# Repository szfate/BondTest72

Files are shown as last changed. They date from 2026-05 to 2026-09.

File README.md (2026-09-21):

# BondTest72

Production test fixture board for bond wire testing, controlled by a Raspberry Pi Pico.
Test signals are routed through CH446X analog crosspoint switches to two 41-pin connectors, on which a replaceable adapter board sits. The adapter board carries the DUT connector and any auxiliary components, keeping the main tester board from wearing out.

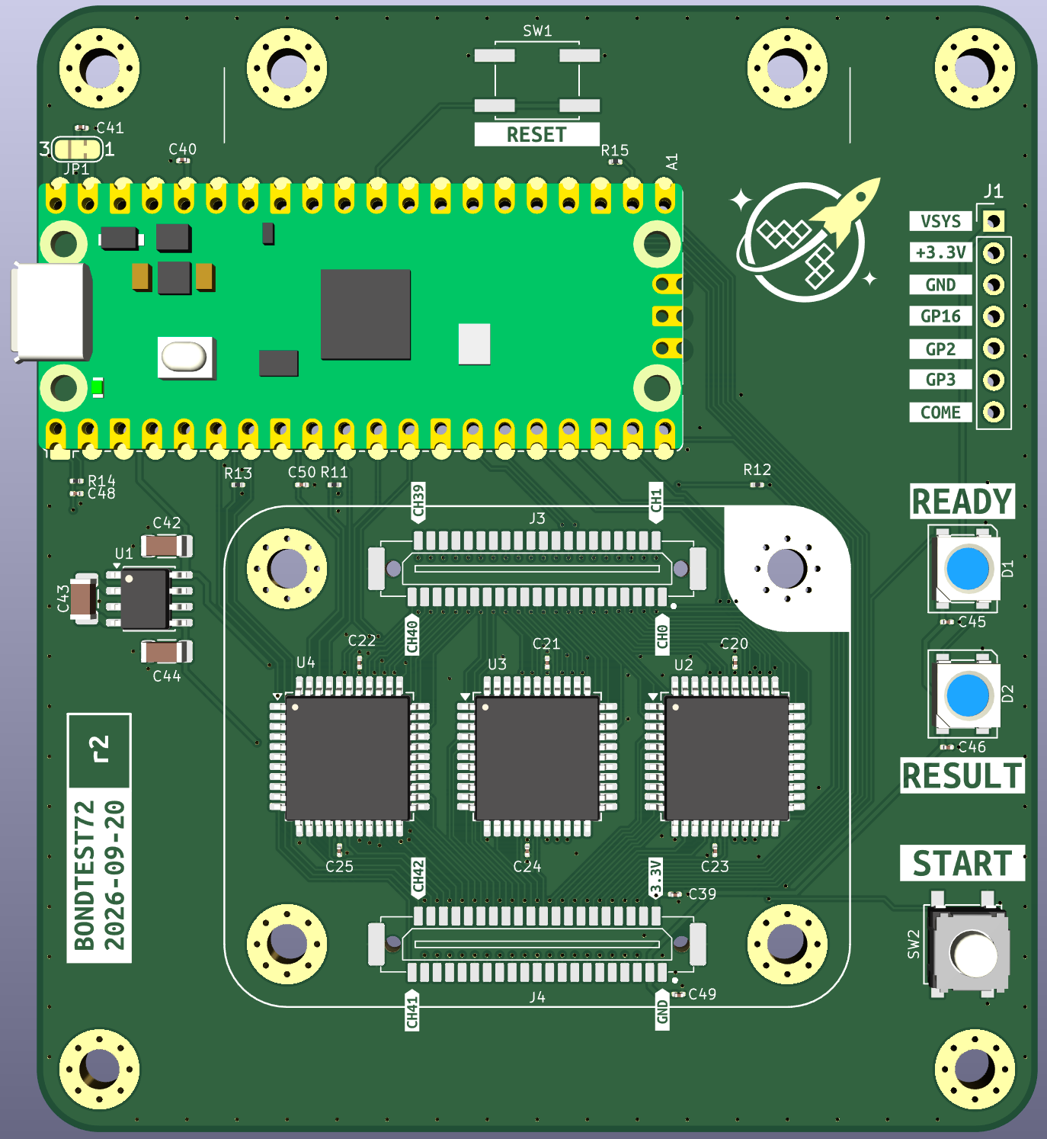
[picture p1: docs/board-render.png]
Board render


## Specifications

| Parameter | Value |
|---|---|
| Revision | r2 |
| Date | 2026-09-20 |
| Board size | 80 × 90 mm |
| Layers | 4 (F.Cu / In1.Cu / In2.Cu / B.Cu) |
| Thickness | 1.6 mm FR4 |

## Power

The board is powered from the Pico's USB VBUS rail. The TPS7A0533 LDO provides an optional quiet +3.3VADC rail as an alternative ADC reference, in case the main +3.3V rail from the Pico's onboard DCDC is too noisy. In practice the application only requires ~0.1 V accuracy, so the main rail is likely sufficient.

An ICL7660 charge-pump voltage inverter (or equivalent) generates the negative VEE rail required by the CH446X analog crosspoint switches.

## Operator Interface

A single push button serves as the START control. The two SK6812 RGB LEDs serve as status indicators. Both the LEDs and the button sit on the right edge of the board so the prodcution panel cannot cover them.

## Signal Routing

Four CH446X analog crosspoint switches fan test signals out from the Pico GPIO/ADC lines to the 41-pin connectors (J3 / J4). These connect to a removable **adapter board** rather than directly to the DUT. The adapter board carries the DUT-side connector (the high-wear part) and any auxiliary components needed for a given test configuration — for example, diodes for self-testing or a small memory chip for wear-cycle monitoring. Replacing the adapter board instead of the whole fixture avoids discarding the tester after the DUT connector wears out (~100 cycles). Solder jumpers on the main board provide flexibility to work around any schematic design flaws discovered after fabrication.

## Revision History

### r2 (2026-09-21)

Schematic:
- Neighbour testing removed, replaced with 10 µA / 100 µA / 1 mA current sources; pullup resistors (280 kΩ / 27.4 kΩ / 2.49 kΩ) sized from the expected diode voltage drop at each current
- ICL7660 (or alternative) added for the negative VEE supply
- 100 kΩ pulldown on Pico pad 22 (CON6, EEPROM SIO)
- 10 kΩ pullup on Pico pad 1 (START) per the RP2350 A2 errata
- 120 pF capacitor added to the ADC sensing net
- Status LEDs reduced from three to two SK6812
- Push button changed to EVP-BT3C4A000; r1's alternate second switch footprint removed

PCB:
- Board size reduced from 80 × 100 mm to 80 × 90 mm
- LEDs and button moved to the right side of the board so the panel no longer covers the LEDs; Space left for button caps
- Feet marks on the bottom silk enlarged from 8 mm to 10 mm

### r1 (2026-05-12)

Initial release. 80 × 100 mm.

## Files

| File | Description |
|---|---|
| `BondTest72.kicad_pro` | KiCad project |
| `BondTest72.kicad_sch` | Schematic |
| `BondTest72.kicad_pcb` | PCB layout |
| `docs/BondTest72-r2-schematic.pdf` | r2 schematic PDF export |
| `docs/BondTest72-r1-schematic.pdf` | r1 schematic PDF export |
| `production/BondTest72-r2.zip` | r2 gerber/fabrication outputs |
| `production/BondTest72-r2-bom.csv` | r2 bill of materials |
| `production/BondTest72-r2-pos.xlsx` | r2 pick-and-place positions |
| `lib.kicad_sym` | Project symbol library |
| `lib.pretty/` | Project footprint library |
| `df9.pretty/` | Additional footprint library |
| `docs/` | Board renders and documentation images |

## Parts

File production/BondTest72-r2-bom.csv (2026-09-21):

Reference | Qty | Value | DNP | Exclude from BOM | Exclude from Board | Footprint | Datasheet | Part Number
A1 | 1 | RaspberryPi_Pico |  |  |  | Module:RaspberryPi_Pico_Common_Unspecified | https://datasheets.raspberrypi.com/pico/pico-datasheet.pdf | C41407547
C20,C21,C22,C23,C24,C25,C39,C45,C46,C48,C49 | 11 | 100n |  |  |  | Capacitor_SMD:C_0201_0603Metric |  | C76939
C40,C41 | 2 | 1u |  |  |  | Capacitor_SMD:C_0201_0603Metric |  | C170153
C42,C43,C44 | 3 | 10u |  |  |  | Capacitor_SMD:C_1206_3216Metric |  | C9807
C50 | 1 | 120pF |  |  |  | Capacitor_SMD:C_0201_0603Metric |  | C161405
D1,D2 | 2 | SK6812 |  |  |  | LED_SMD:LED_SK6812_PLCC4_5.0x5.0mm_P3.2mm | https://cdn-shop.adafruit.com/product-files/1138/SK6812+LED+datasheet+.pdf | C5378720
J1 | 1 | Conn_01x07 | DNP |  |  | Connector_PinHeader_2.54mm:PinHeader_1x07_P2.54mm_Vertical
J3,J4 | 2 | Conn_2Rows-41Pins_MountingPin |  |  |  | df9:DF9-41P-1V |  | C21261706
R11 | 1 | 27.4K |  |  |  | Resistor_SMD:R_0201_0603Metric |  | C273316
R12 | 1 | 2.49k |  |  |  | Resistor_SMD:R_0201_0603Metric |  | C851701
R13 | 1 | 280k |  |  |  | Resistor_SMD:R_0201_0603Metric |  | C778392
R14 | 1 | 10k |  |  |  | Resistor_SMD:R_0201_0603Metric |  | C106225
R15 | 1 | 100k |  |  |  | Resistor_SMD:R_0201_0603Metric |  | C106224
SW1 | 1 | SW_Push |  |  |  | Button_Switch_SMD:SW_SPST_EVQQ2 |  | C713484
SW2 | 1 | SW_Push |  |  |  | Button_Switch_SMD:SW_SPST_EVPBF |  | C4365008
U1 | 1 | ICL7660 |  |  |  | Package_SO:SOIC-8_3.9x4.9mm_P1.27mm | http://datasheets.maximintegrated.com/en/ds/ICL7660-MAX1044.pdf | C356724
U2,U3,U4 | 3 | CH446X |  |  |  | Package_QFP:LQFP-44_10x10mm_P0.8mm |  | C3018882

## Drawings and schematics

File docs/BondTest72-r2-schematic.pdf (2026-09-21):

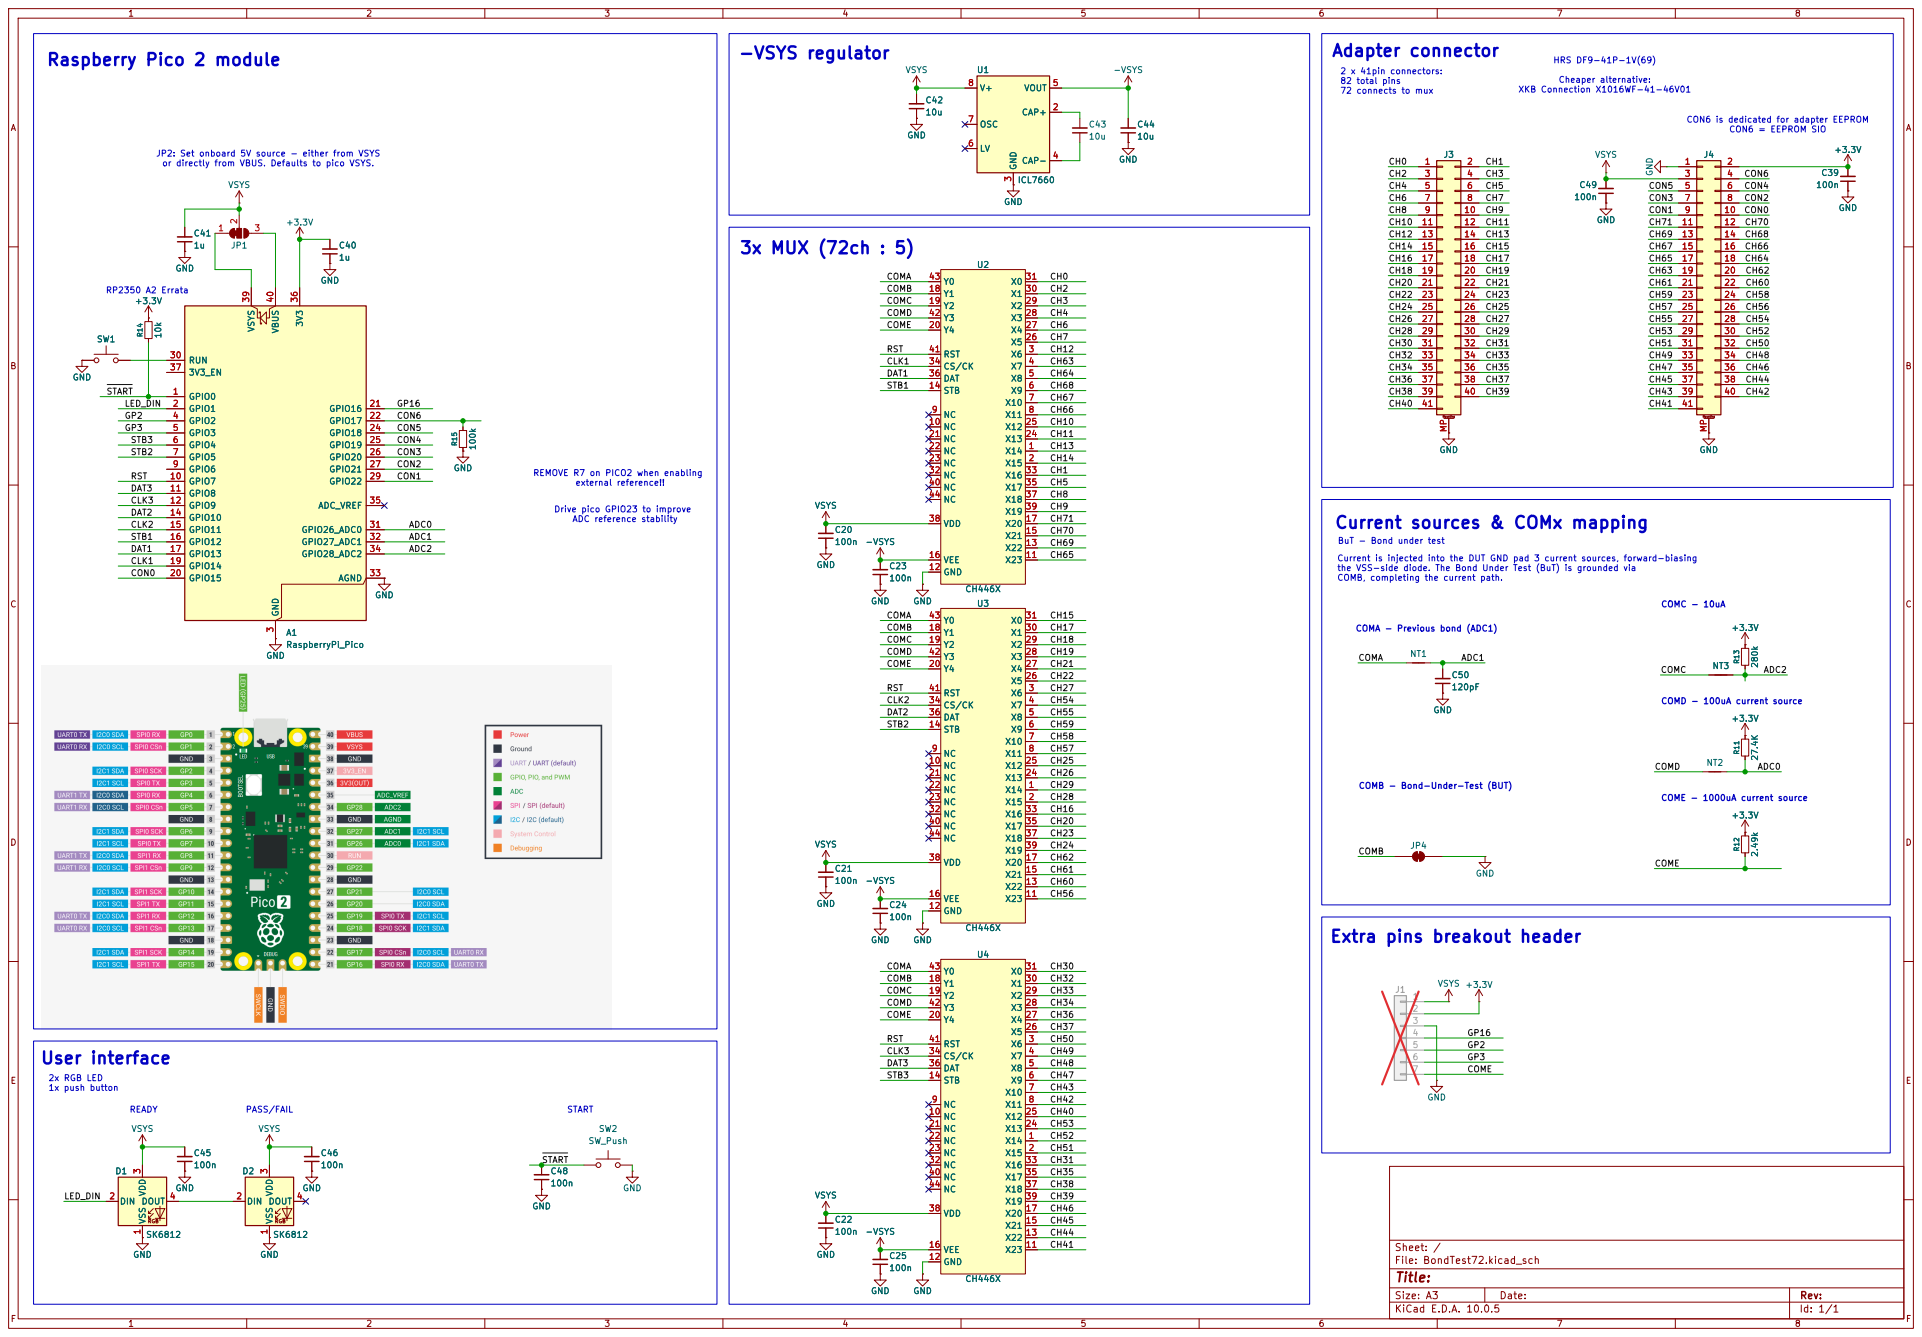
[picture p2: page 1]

CON6 = EEPROM SIO -VSYS regulator

Cheaper alternative: XKB Connection X1016WF-41-46V01 3x MUX (72ch : 5)

CON6 is dedicated for adapter EEPROM

JP2: Set onboard 5V source - either from VSYS

COMA - Previous bond (ADC1) Current is injected into the DUT GND pad 3 current sources, forward-biasing

the VSS-side diode. The Bond Under Test (BuT) is grounded via COMB, completing the current path. START

Extra pins breakout header

Size: A3 | Rev: | F Date:
KiCad E.D.A. 10.0.5 | Id: 1/1

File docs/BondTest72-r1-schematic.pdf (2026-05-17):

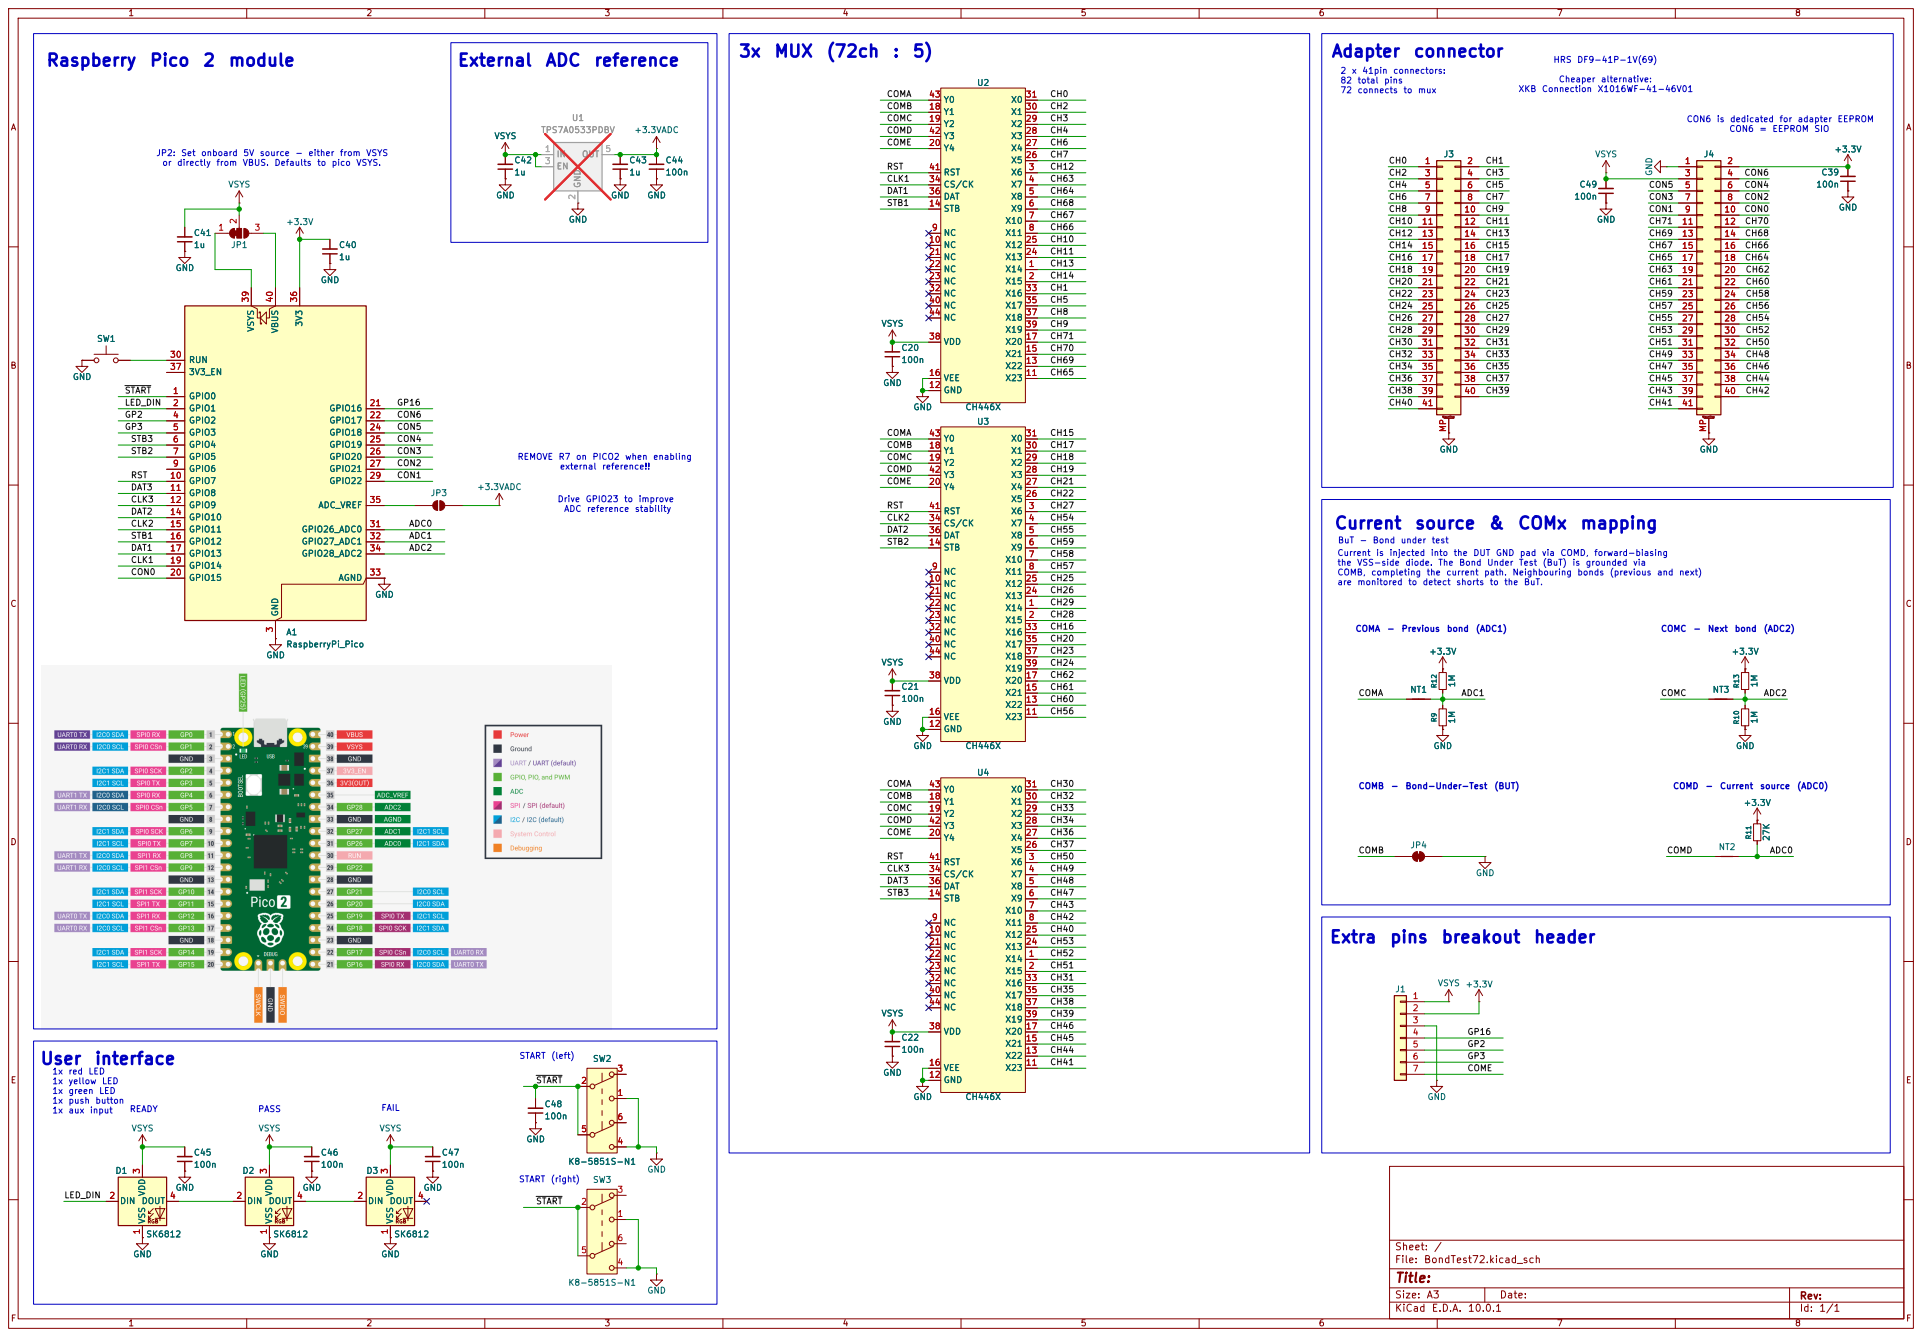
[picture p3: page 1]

Cheaper alternative: XKB Connection X1016WF-41-46V01 Adapter connector

or directly from VBUS. Defaults to pico VSYS. Raspberry Pico 2 module

2 x 41pin connectors: 82 total pins 72 connects to mux

CON6 is dedicated for adapter EEPROM

CON6 = EEPROM SIO Current source & COMx mapping

JP2: Set onboard 5V source - either from VSYS

REMOVE R7 on PICO2 when enabling external reference!! Drive GPIO23 to improve ADC reference stability

BuT - Bond under test COMA - Previous bond (ADC1)
Current is injected into the DUT GND pad via COMD, forward-biasing

the VSS-side diode. The Bond Under Test (BuT) is grounded via COMB, completing the current path. Neighbouring bonds (previous and next) are monitored to detect shorts to the BuT. START (left)

COMD - Current source (ADC0) PASS User interface 1x red LED

COMB - Bond-Under-Test (BUT)

Size: A3 | Rev: | F Date:
KiCad E.D.A. 10.0.1 | Id: 1/1

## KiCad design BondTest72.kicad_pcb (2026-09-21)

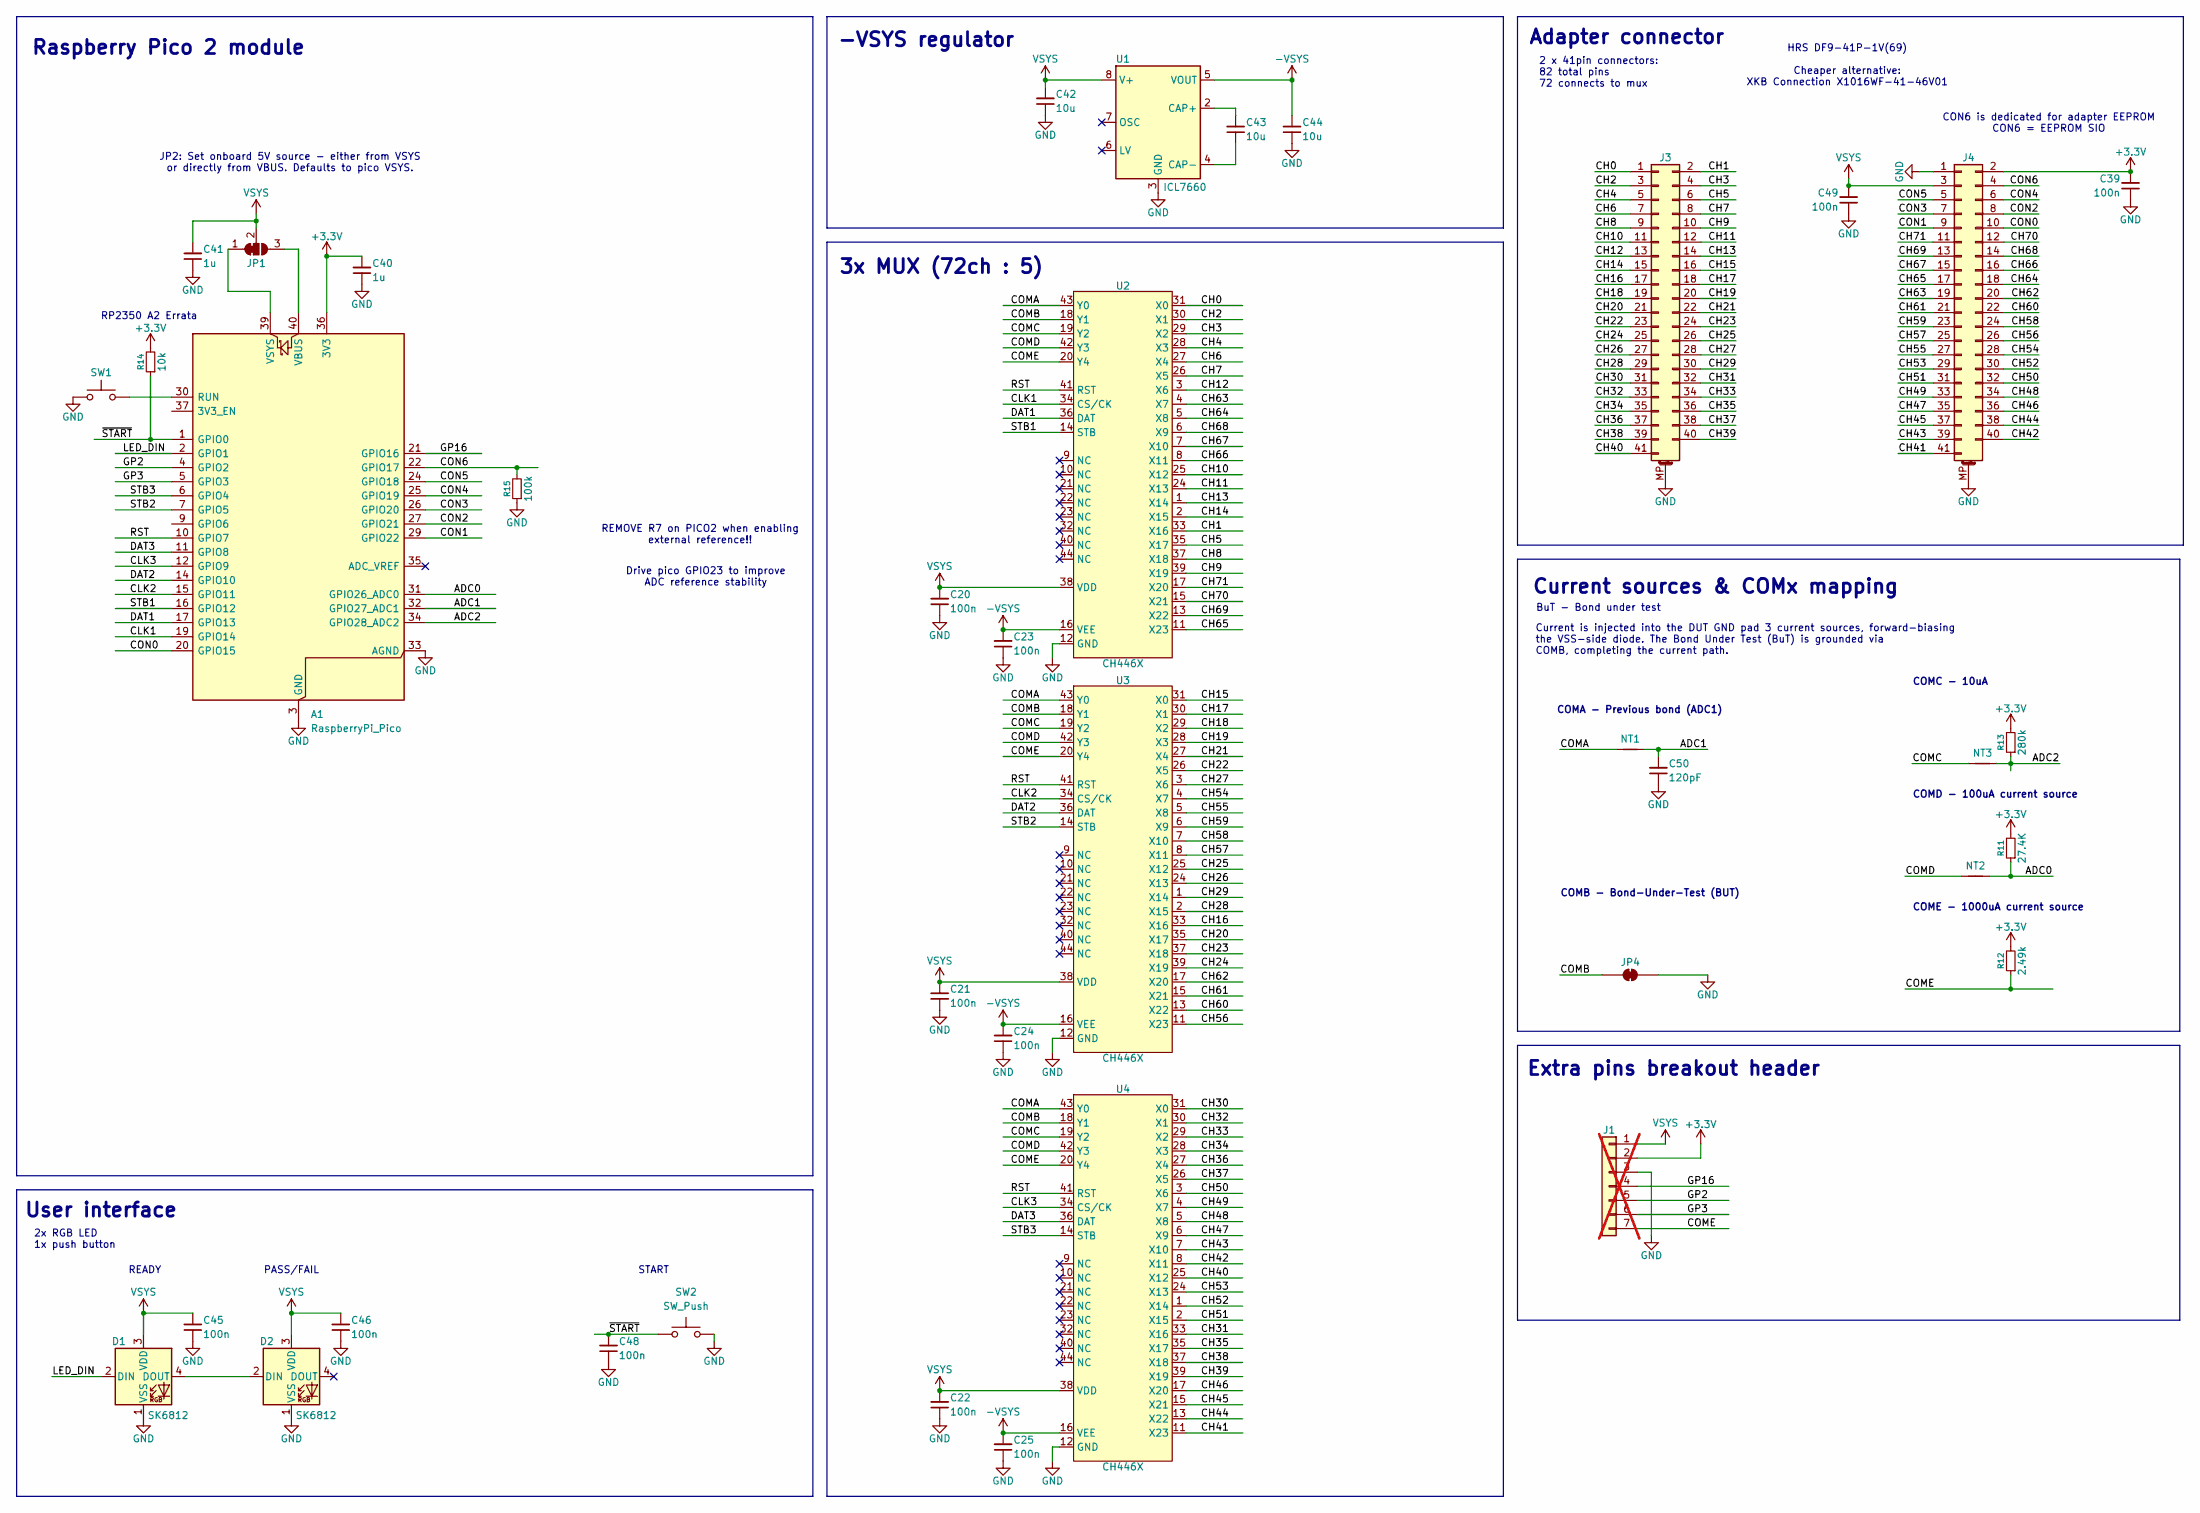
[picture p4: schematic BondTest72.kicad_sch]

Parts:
A1: RaspberryPi_Pico; RaspberryPi_Pico_Common_Unspecified; Part Number C41407547
C20, C21, C22, C23, C24, C25, C39, C45, C46, C48, C49: 100n; C_0201_0603Metric; Part Number C76939
C40, C41: 1u; C_0201_0603Metric; Part Number C170153
C42, C43, C44: 10u; C_1206_3216Metric; Part Number C9807
C50: 120pF; C_0201_0603Metric; Part Number C161405
D1, D2: SK6812; LED_SK6812_PLCC4_5.0x5.0mm_P3.2mm; Part Number C5378720
J1: Conn_01x07; PinHeader_1x07_P2.54mm_Vertical; not fitted
J3, J4: Conn_2Rows-41Pins_MountingPin; DF9-41P-1V; Part Number C21261706
JP1: SolderJumper_3_Bridged12; SolderJumper-3_P1.3mm_Bridged12_RoundedPad1.0x1.5mm_NumberL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
JP4: SolderJumper_2_Bridged; SolderJumper-2_P1.3mm_Bridged_RoundedPad1.0x1.5mm
NT1, NT2, NT3: NetTie_2; NetTie-2_SMD_Pad0.15mm
R11: 27.4K; R_0201_0603Metric; Part Number C273316
R12: 2.49k; R_0201_0603Metric; Part Number C851701
R13: 280k; R_0201_0603Metric; Part Number C778392
R14: 10k; R_0201_0603Metric; Part Number C106225
R15: 100k; R_0201_0603Metric; Part Number C106224
SW1: SW_Push; SW_SPST_EVQQ2; Part Number C713484
SW2: SW_Push; SW_SPST_EVPBF; Part Number C4365008
U1: ICL7660; SOIC-8_3.9x4.9mm_P1.27mm; Part Number C356724
U2, U3, U4: CH446X; LQFP-44_10x10mm_P0.8mm; Part Number C3018882

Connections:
+3.3V: A1.36 (3V3), C39.2, C40.2, J1.2, J4.2, R11.2, R12.2, R13.2, R14.2
-VSYS: C23.2, C24.2, C25.2, C44.2, U1.5 (VOUT), U2.16 (VEE), U3.16 (VEE), U4.16 (VEE)
/ADC0: A1.31 (GPIO26_ADC0), NT2.2, R11.1
/ADC1: A1.32 (GPIO27_ADC1), C50.2, NT1.2
/ADC2: A1.34 (GPIO28_ADC2), NT3.2, R13.1
/CH0: J3.1, U2.31 (X0)
/CH1: J3.2, U2.33 (X16)
/CH2: J3.3, U2.30 (X1)
/CH3: J3.4, U2.29 (X2)
/CH4: J3.5, U2.28 (X3)
/CH5: J3.6, U2.35 (X17)
/CH6: J3.7, U2.27 (X4)
/CH7: J3.8, U2.26 (X5)
/CH8: J3.9, U2.37 (X18)
/CH9: J3.10, U2.39 (X19)
/CH10: J3.11, U2.25 (X12)
/CH11: J3.12, U2.24 (X13)
/CH12: J3.13, U2.3 (X6)
/CH13: J3.14, U2.1 (X14)
/CH14: J3.15, U2.2 (X15)
/CH15: J3.16, U3.31 (X0)
/CH16: J3.17, U3.33 (X16)
/CH17: J3.18, U3.30 (X1)
/CH18: J3.19, U3.29 (X2)
/CH19: J3.20, U3.28 (X3)
/CH20: J3.21, U3.35 (X17)
/CH21: J3.22, U3.27 (X4)
/CH22: J3.23, U3.26 (X5)
/CH23: J3.24, U3.37 (X18)
/CH24: J3.25, U3.39 (X19)
/CH25: J3.26, U3.25 (X12)
/CH26: J3.27, U3.24 (X13)
/CH27: J3.28, U3.3 (X6)
/CH28: J3.29, U3.2 (X15)
/CH29: J3.30, U3.1 (X14)
/CH30: J3.31, U4.31 (X0)
/CH31: J3.32, U4.33 (X16)
/CH32: J3.33, U4.30 (X1)
/CH33: J3.34, U4.29 (X2)
/CH34: J3.35, U4.28 (X3)
/CH35: J3.36, U4.35 (X17)
/CH36: J3.37, U4.27 (X4)
/CH37: J3.38, U4.26 (X5)
/CH38: J3.39, U4.37 (X18)
/CH39: J3.40, U4.39 (X19)
/CH40: J3.41, U4.25 (X12)
/CH41: J4.41, U4.11 (X23)
/CH42: J4.40, U4.8 (X11)
/CH43: J4.39, U4.7 (X10)
/CH44: J4.38, U4.13 (X22)
/CH45: J4.37, U4.15 (X21)
/CH46: J4.36, U4.17 (X20)
/CH47: J4.35, U4.6 (X9)
/CH48: J4.34, U4.5 (X8)
/CH49: J4.33, U4.4 (X7)
/CH50: J4.32, U4.3 (X6)
/CH51: J4.31, U4.2 (X15)
/CH52: J4.30, U4.1 (X14)
/CH53: J4.29, U4.24 (X13)
/CH54: J4.28, U3.4 (X7)
/CH55: J4.27, U3.5 (X8)
/CH56: J4.26, U3.11 (X23)
/CH57: J4.25, U3.8 (X11)
/CH58: J4.24, U3.7 (X10)
/CH59: J4.23, U3.6 (X9)
/CH60: J4.22, U3.13 (X22)
/CH61: J4.21, U3.15 (X21)
/CH62: J4.20, U3.17 (X20)
/CH63: J4.19, U2.4 (X7)
/CH64: J4.18, U2.5 (X8)
/CH65: J4.17, U2.11 (X23)
/CH66: J4.16, U2.8 (X11)
/CH67: J4.15, U2.7 (X10)
/CH68: J4.14, U2.6 (X9)
/CH69: J4.13, U2.13 (X22)
/CH70: J4.12, U2.15 (X21)
/CH71: J4.11, U2.17 (X20)
/CLK1: A1.19 (GPIO14), U2.34 (CS/CK)
/CLK2: A1.15 (GPIO11), U3.34 (CS/CK)
/CLK3: A1.12 (GPIO9), U4.34 (CS/CK)
/COMA: NT1.1, U2.43 (Y0), U3.43 (Y0), U4.43 (Y0)
/COMB: JP4.1 (A), U2.18 (Y1), U3.18 (Y1), U4.18 (Y1)
/COMC: NT3.1, U2.19 (Y2), U3.19 (Y2), U4.19 (Y2)
/COMD: NT2.1, U2.42 (Y3), U3.42 (Y3), U4.42 (Y3)
/COME: J1.7, R12.1, U2.20 (Y4), U3.20 (Y4), U4.20 (Y4)
/CON0: A1.20 (GPIO15), J4.10
/CON1: A1.29 (GPIO22), J4.9
/CON2: A1.27 (GPIO21), J4.8
/CON3: A1.26 (GPIO20), J4.7
/CON4: A1.25 (GPIO19), J4.6
/CON5: A1.24 (GPIO18), J4.5
/CON6: A1.22 (GPIO17), J4.4, R15.2
/DAT1: A1.17 (GPIO13), U2.36 (DAT)
/DAT2: A1.14 (GPIO10), U3.36 (DAT)
/DAT3: A1.11 (GPIO8), U4.36 (DAT)
/GP2: A1.4 (GPIO2), J1.5
/GP3: A1.5 (GPIO3), J1.6
/GP16: A1.21 (GPIO16), J1.4
/LED_DIN: A1.2 (GPIO1), D1.2 (DIN)
/RST: A1.10 (GPIO7), U2.41 (RST), U3.41 (RST), U4.41 (RST)
/STB1: A1.16 (GPIO12), U2.14 (STB)
/STB2: A1.7 (GPIO5), U3.14 (STB)
/STB3: A1.6 (GPIO4), U4.14 (STB)
/~START: A1.1 (GPIO0), C48.2, R14.1, SW2.1
GND: A1.3 (GND), A1.8 (GND), A1.13 (GND), A1.18 (GND), A1.23 (GND), A1.28 (GND), A1.33 (AGND), A1.38 (GND), C20.1, C21.1, C22.1, C23.1, C24.1, C25.1, C39.1, C40.1, C41.1, C42.1, C44.1, C45.1, C46.1, C48.1, C49.1, C50.1, D1.1 (VSS), D2.1 (VSS), J1.3, J3.MP (MountPin), J4.1, J4.MP (MountPin), JP4.2 (B), R15.1, SW1.1, SW2.2, U1.3 (GND), U2.12 (GND), U3.12 (GND), U4.12 (GND)
unnamed: A1.30 (RUN), SW1.2
unnamed: A1.40 (VBUS), JP1.3 (B)
unnamed: A1.39 (VSYS), JP1.1 (A)
unnamed: D1.4 (DOUT), D2.2 (DIN)
unnamed: C43.2, U1.2 (CAP+)
unnamed: C43.1, U1.4 (CAP-)
VSYS: C20.2, C21.2, C22.2, C41.2, C42.2, C45.2, C46.2, C49.2, D1.3 (VDD), D2.3 (VDD), J1.1, J4.3, JP1.2 (C), U1.8 (V+), U2.38 (VDD), U3.38 (VDD), U4.38 (VDD)

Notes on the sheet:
3x MUX (72ch : 5)
Adapter connector
HRS DF9-41P-1V(69) Cheaper alternative: XKB Connection X1016WF-41-46V01
COMB - Bond-Under-Test (BUT)
READY
Raspberry Pico 2 module
Drive pico GPIO23 to improve ADC reference stability
COMD - 100uA current source
CON6 is dedicated for adapter EEPROM CON6 = EEPROM SIO
2x RGB LED 1x push button
REMOVE R7 on PICO2 when enabling external reference!!
Current sources & COMx mapping
COMC - 10uA
User interface
BuT - Bond under test
COME - 1000uA current source
-VSYS regulator
RP2350 A2 Errata
JP2: Set onboard 5V source - either from VSYS or directly from VBUS. Defaults to pico VSYS.
START
PASS/FAIL
2 x 41pin connectors: 82 total pins 72 connects to mux
Extra pins breakout header
COMA - Previous bond (ADC1)
Current is injected into the DUT GND pad 3 current sources, forward-biasing the VSS-side diode. The Bond Under Test (BuT) is grounded via COMB, completing the current path.

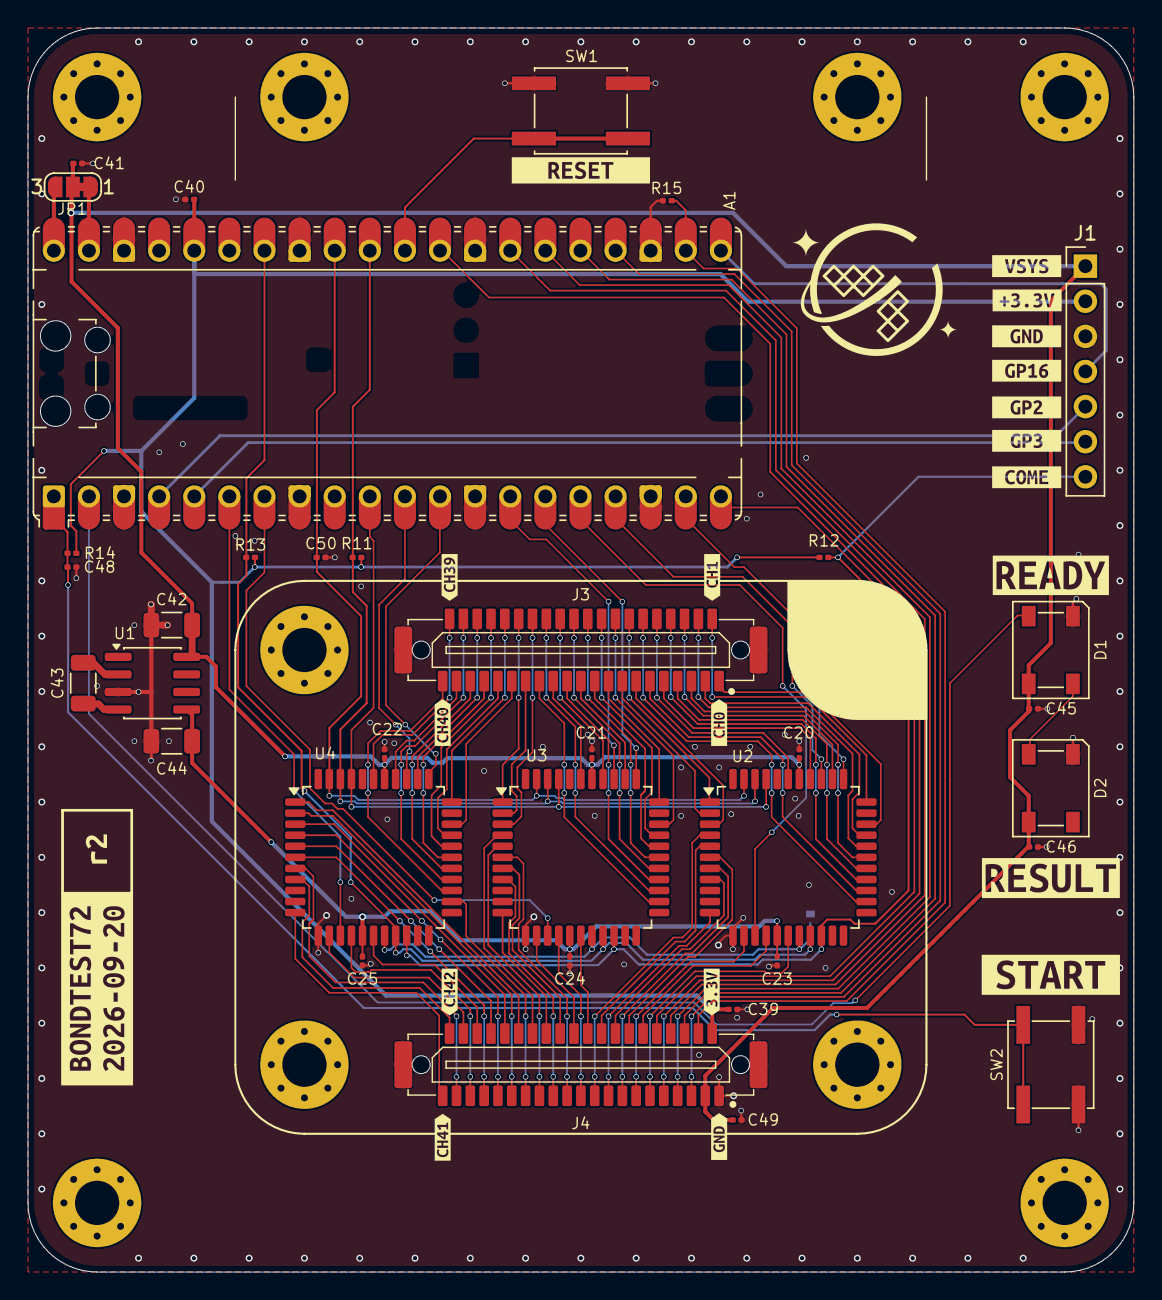
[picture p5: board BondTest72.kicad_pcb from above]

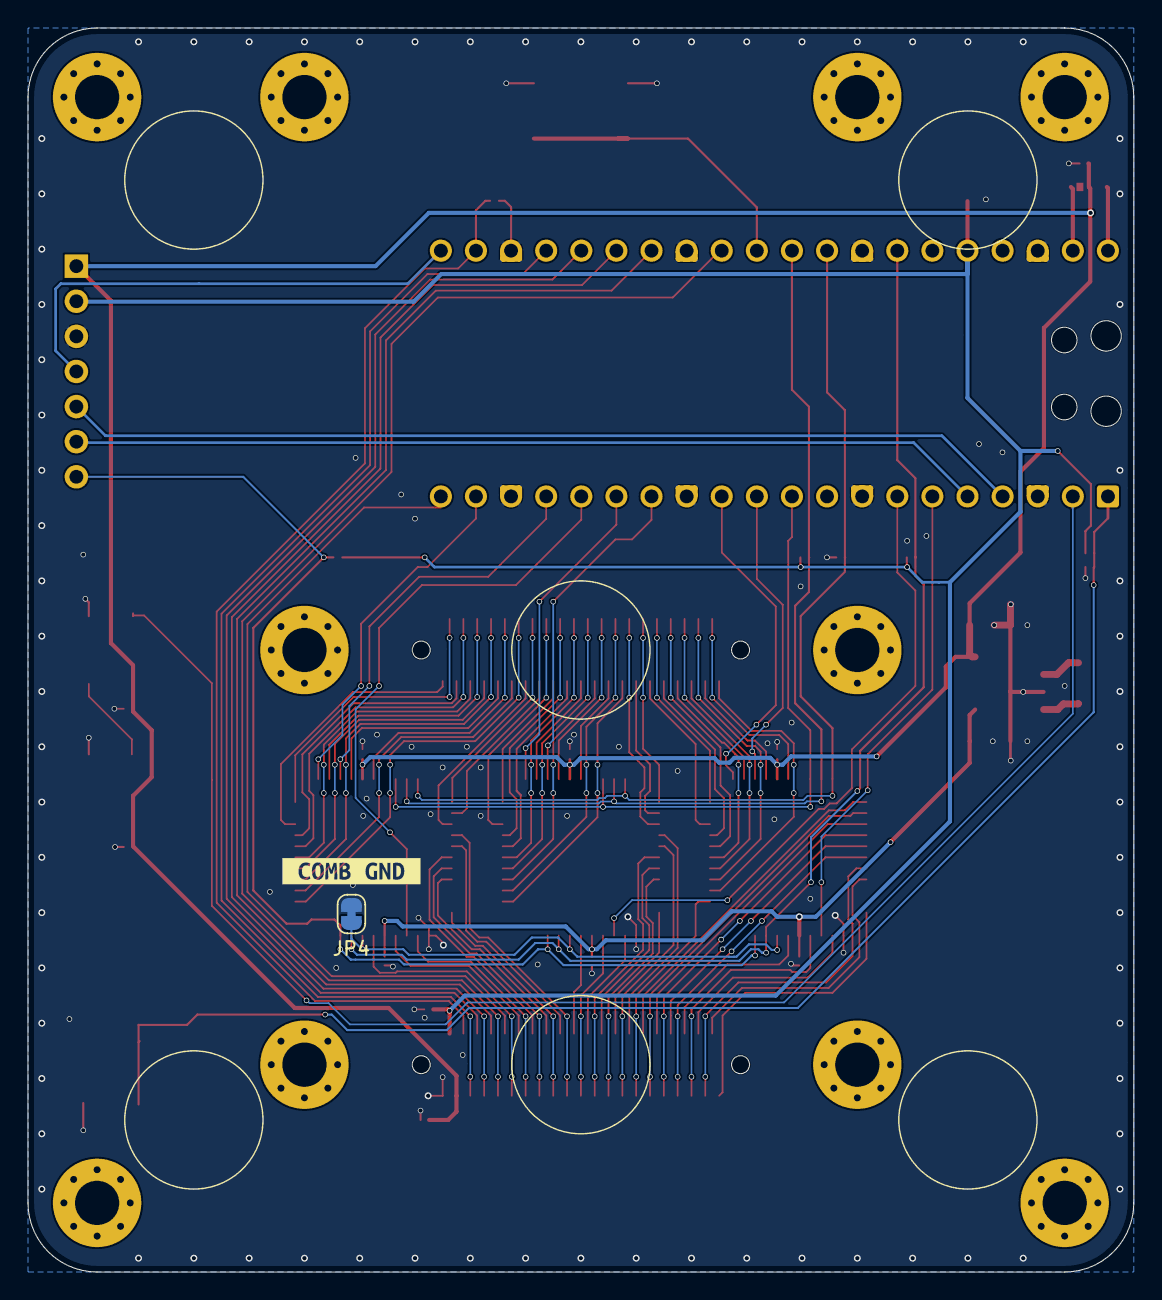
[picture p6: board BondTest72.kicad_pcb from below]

Board: 4 copper layers, 80.0 x 90.0 mm, 61 parts (2 on the bottom side), 112 nets.

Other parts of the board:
kibuzzard-6A01F8AF: G***; kibuzzard-6A01F8AF
kibuzzard-6A01F8BD: G***; kibuzzard-6A01F8BD
kibuzzard-6A01F62B: G***; kibuzzard-6A01F62B
kibuzzard-6A01F65D: G***; kibuzzard-6A01F65D
kibuzzard-6A01F81D: G***; kibuzzard-6A01F81D
kibuzzard-6A01F87F: G***; kibuzzard-6A01F87F
kibuzzard-6A01F88E: G***; kibuzzard-6A01F88E
kibuzzard-6A01F618: G***; kibuzzard-6A01F618
kibuzzard-6A01F644: G***; kibuzzard-6A01F644
kibuzzard-6A01F655: G***; kibuzzard-6A01F655
kibuzzard-6A01F806: G***; kibuzzard-6A01F806
kibuzzard-6A01FB9A: G***; kibuzzard-6A01FB9A
kibuzzard-6A01FE13: G***; kibuzzard-6A01FE13
kibuzzard-6A02A7B4: G***; kibuzzard-6A02A7B4
kibuzzard-6A02FF2D: G***; kibuzzard-6A02FF2D
kibuzzard-6A02760F: G***; kibuzzard-6A02760F
kibuzzard-6A027603: G***; kibuzzard-6A027603
kibuzzard-6A030225: G***; kibuzzard-6A030225
kibuzzard-6AAFDF39: G***; kibuzzard-6AAFDF39
kibuzzard-6AAFDFCA: G***; kibuzzard-6AAFDFCA
kibuzzard-6AAFFF2E: G***; kibuzzard-6AAFFF2E
kibuzzard-6AAFFF26: G***; kibuzzard-6AAFFF26

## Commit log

2026-05-17 Initial commit. Adding already fabricated r1 files.
    [BondTest72.kicad_pcb, BondTest72.kicad_sch]
2026-09-21 - r2 update. Notes in README.md
    [BondTest72-r2-bom.csv, BondTest72.kicad_pcb, BondTest72.kicad_sch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]
